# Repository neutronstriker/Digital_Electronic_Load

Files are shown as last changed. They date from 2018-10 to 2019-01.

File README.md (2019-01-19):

# Digital_Electronic_Load
An Electronic Load based on Arduino and some analog components
Components used are:
Arduino Nano-1
OLED I2C display 0.96Inch - 1
TPL0102-100PWR I2C DIGITAL PORT -1
LM358  DUAL OPAMP -1
INA226 Shunt Current / Power sensor - 1
2N3055 - NPN Power transistor -1
1 OHM / 10W resistor -1

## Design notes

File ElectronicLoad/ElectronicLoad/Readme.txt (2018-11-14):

/*
 * Readme.txt
 *
 * Created: 28-05-2016 18:02:26
 *  Author: neutron
 */ 
 I have again done the same mistake I did on PPS, I have enabled WDT in code and now I am unable to upload code because
 bootloader doesn't know about WDT. SO I have to connect USBASP and flash the nano board with the bootloader file atmega328_WD_MODS_16MHZ_57600.hex present
 in AVR Bootloader folder.

 Only then I will be able to upload code.

 I should also change the bootloaders of other nanos on the same day.

 The above thing is done on DT28-05-2016

 Dt29-05-2016:
 I faced recently a lot a device hanging issues these started earlier also but since I didnot do any extensive testing It was not being
 able to surface. So I found out that this was rarely happening because the knob button and its multiplier changing code.

 Since I had changed the wdt period to 4s instead of 2S. I figured out this was happening because of I2C bus. So I used
 different pull up resistors, As I thought 10k may be too high pull up and as a result the bus capacitance was not meeting
 the required rise time and fall time at 400khz. So I enabled internal pullups still the problem was there. So I reduced 
 the resistors to 2.2k still after sometime the problem surfaced again. 
 
 Finally I found out by checking is that INA226 was creating the problem. Because SSD1306 OLED driver has I2C internal Clamping for
 3.3V, but INA226 and TPL0102 was powered by 5V, but TPL0102 was written on event driven basis however INA226 and SSD1306 was accessed
 on loop.

 So as soon as SSD1306 was enabled I2C bus voltage was not stable it was around 3.8Vrms but after using 2.2k resistors it was 2.58Vrms
 So what I did was that I changed the supply voltage for INA226 to 3.3V it worked for sometime but again the problem started and the
 final bug was discovered which was wiring and length matching issue.  Well not exactly length matching but quite like it as Only for INA226
 the I2C SDA and SCL lines for not comming from a single point and wire lengths were not same. One wire was coming from A4, A5 pins and other
 was comming from OLED I2C pins. So one of them getting delayed.

 So I removed the I2C line which was coming from OLED i2C pin and connected from source forming a proper star configuration.

 So we should always make sure either it is a multi drop or star but make sure the I2C bus line lengths for both DATA and CLK for any device
is always same.

 So After this problem was solved so  I tried to put the supply voltage back to 5V but still there was a problem.
 So i Put it back to 3.3V.

 Now it is working but sometimes still it hangs and watchdog resets the device after 4S.

 Also the clock of I2C bus has been reduced to 100khz in order to cope up with these bus voltage and rise time issues.

 I also did the experiment of remove the gnd connection to load and then weird things started happening, even when we were supplying
 around 1mV only it was sourcing around 160mA on 5V. And when current was set went even mad.

 So I connected the ground back. 

 I also did the reverse connection test when the device was off and PPS was set to 2.5V, PPS went into OVERLOAD. Even when ELOAD was online
 PPS said OVERLOAD at 10mA set on ELOAD and Voltage on PPS 1.98V.

 I checked the bias current issue, and found that the current from OPAMP to MMBT3904 was negligibly small until saturation was hit.
 After saturation was hit it increased to a max 42mA as shown in Display by INA226 but Multimeter showed 46.5mA and also 
 I found that this means we need to calibrate either one of PPS or ELOAD. So there is a calibration issue between PPS and ELOAD.
 The extra current shown in ELOAD is not because of OPAMP output unless there in noload supply or It is saturated.

 Date:03-April-2017:
 Changed the INA226 sensor address to 0x41 in init_platform() because I am using external sensor breakout board which is programmed to do that.

 Date:03-June-2017:
 INA226 based Hang issue fixed now, it seems SCL to ina226 was not soldered properly also I changed the supply voltage of INA226 to 5V (Arduino
 NANO 5V OUTPUT) instead of 3.3V. Also enable the debounce delay in ISR0 which was disabled previously.

 Dt:29-10-2018:
 Added Serial command capability for setting current and turning on and off the load.
 This was done in a hurry for a specific task, so we will need to clean it up sometime when possible.

 Dt:14-11-2018:
 Added temp?, tset and help commands
 which will get the LM35 temperature value, set the safe operating temperature threshold and display commands usage

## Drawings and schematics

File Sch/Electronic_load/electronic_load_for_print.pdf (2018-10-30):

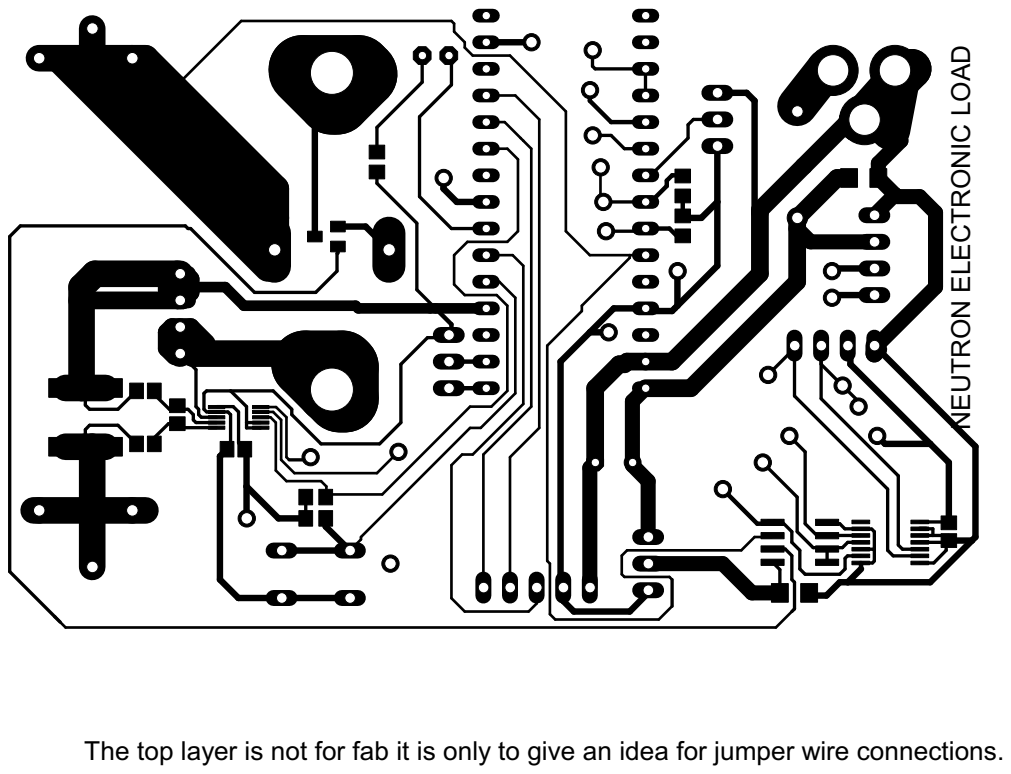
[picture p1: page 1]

The top layer is not for fab it is only to give an idea for jumper wire connections.

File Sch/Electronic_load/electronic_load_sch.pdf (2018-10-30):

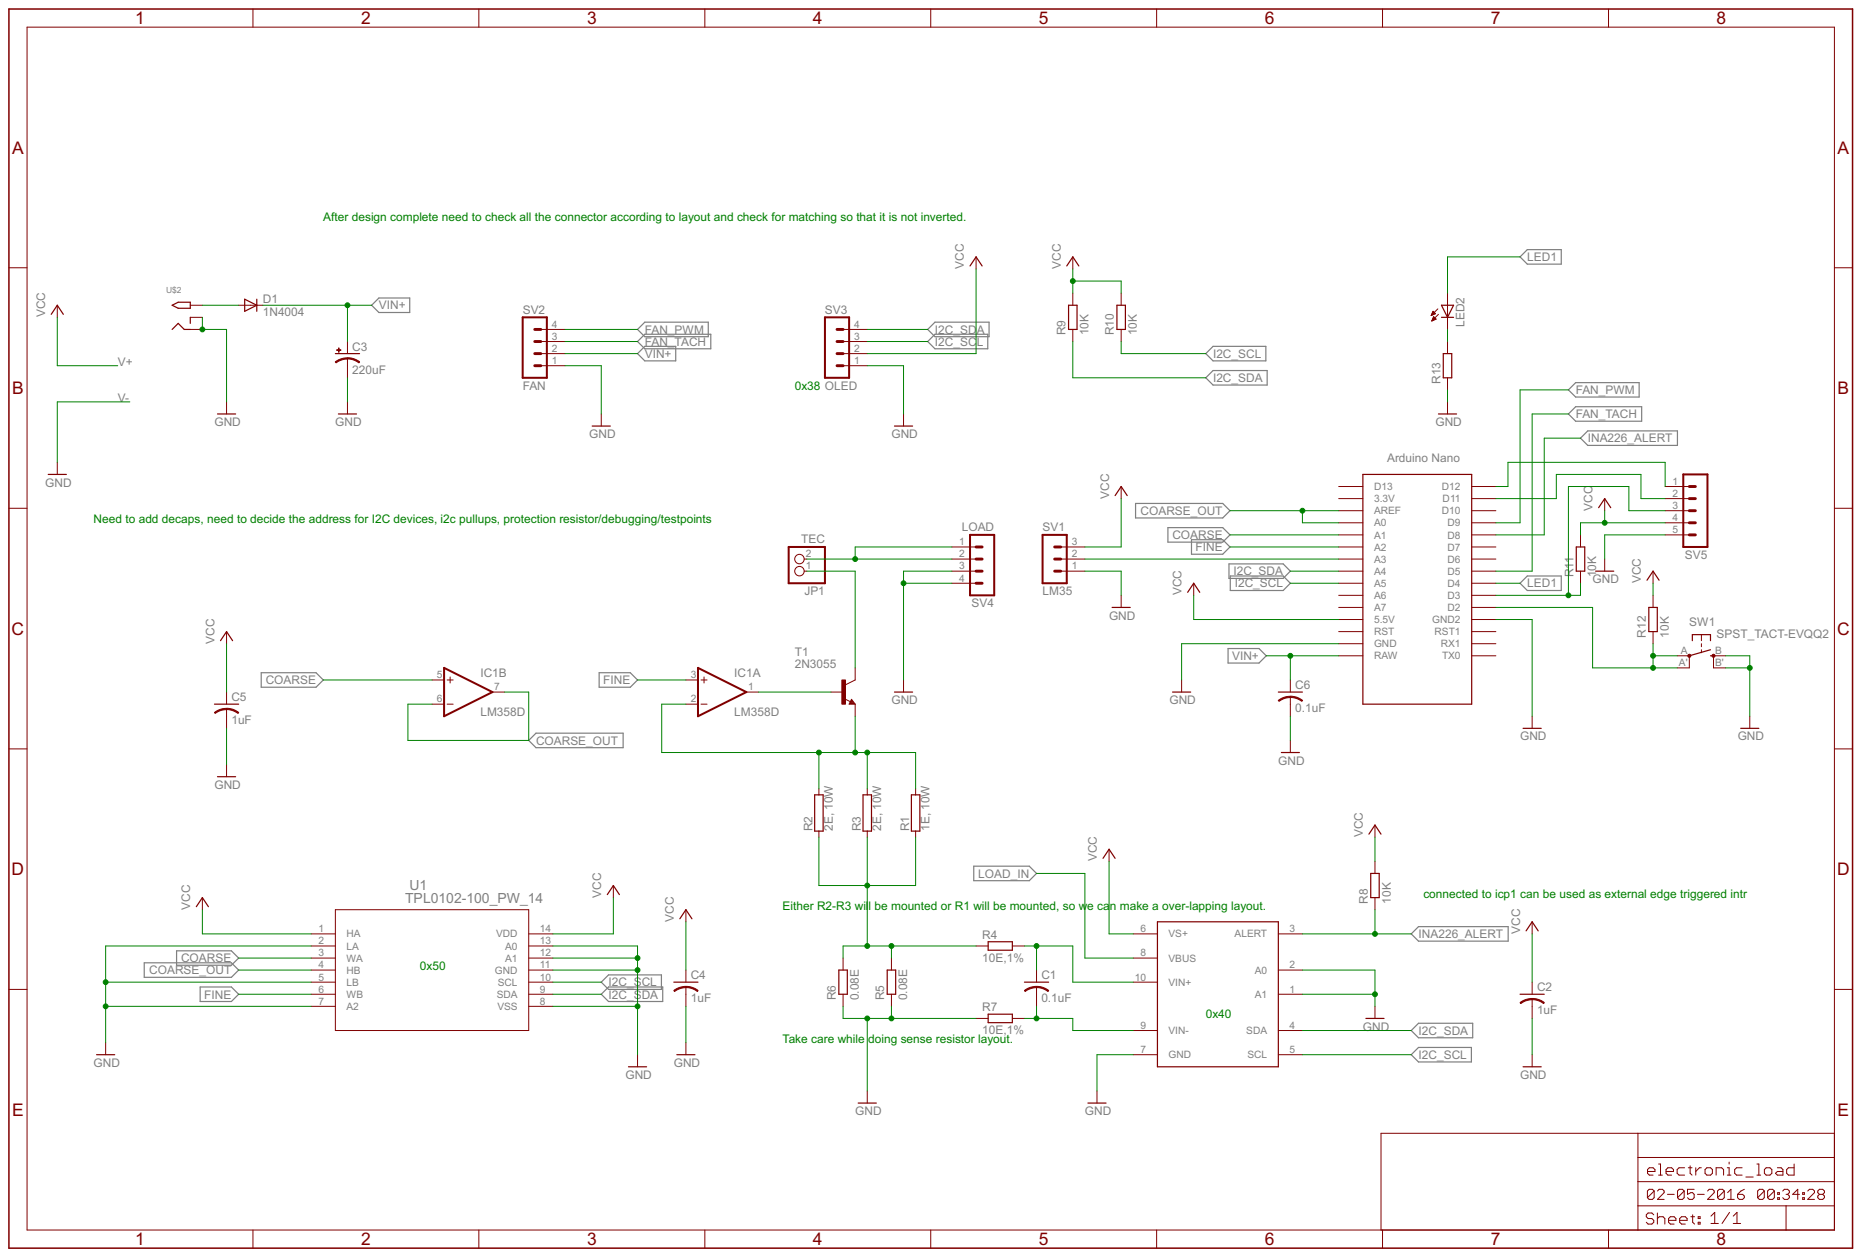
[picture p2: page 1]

After design complete need to check all the connector according to layout and check for matching so that it is not inverted.

Need to add decaps, need to decide the address for I2C devices, i2c pullups, protection resistor/debugging/testpoints

connected to icp1 can be used as external edge triggered intr

Either R2-R3 will be mounted or R1 will be mounted, so we can make a over-lapping layout.

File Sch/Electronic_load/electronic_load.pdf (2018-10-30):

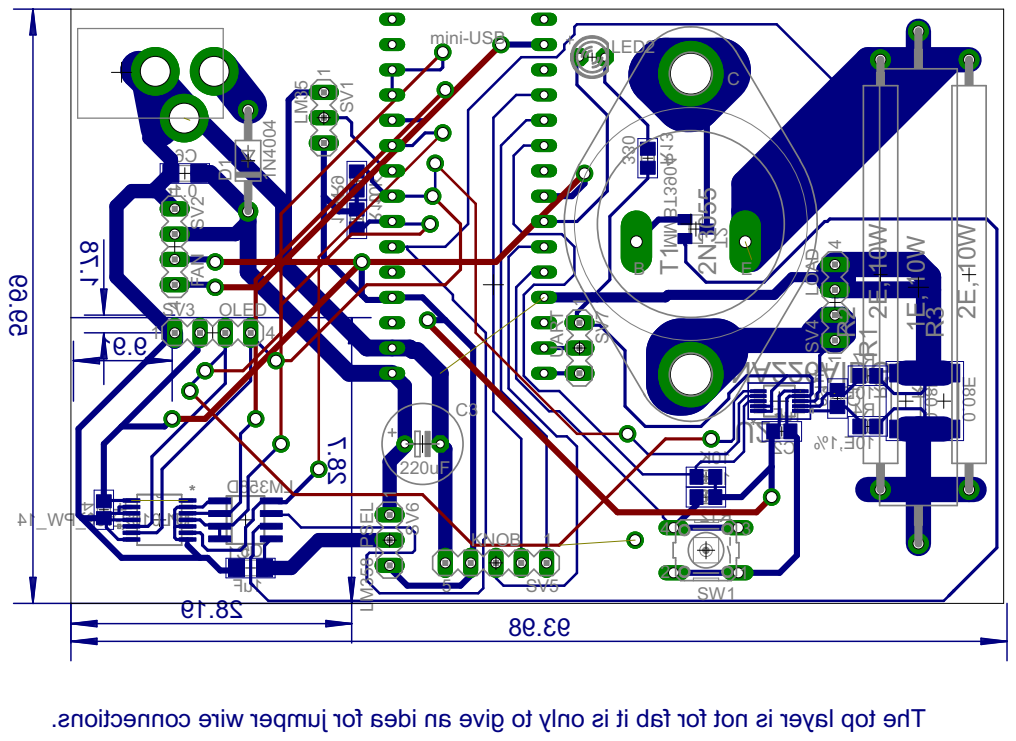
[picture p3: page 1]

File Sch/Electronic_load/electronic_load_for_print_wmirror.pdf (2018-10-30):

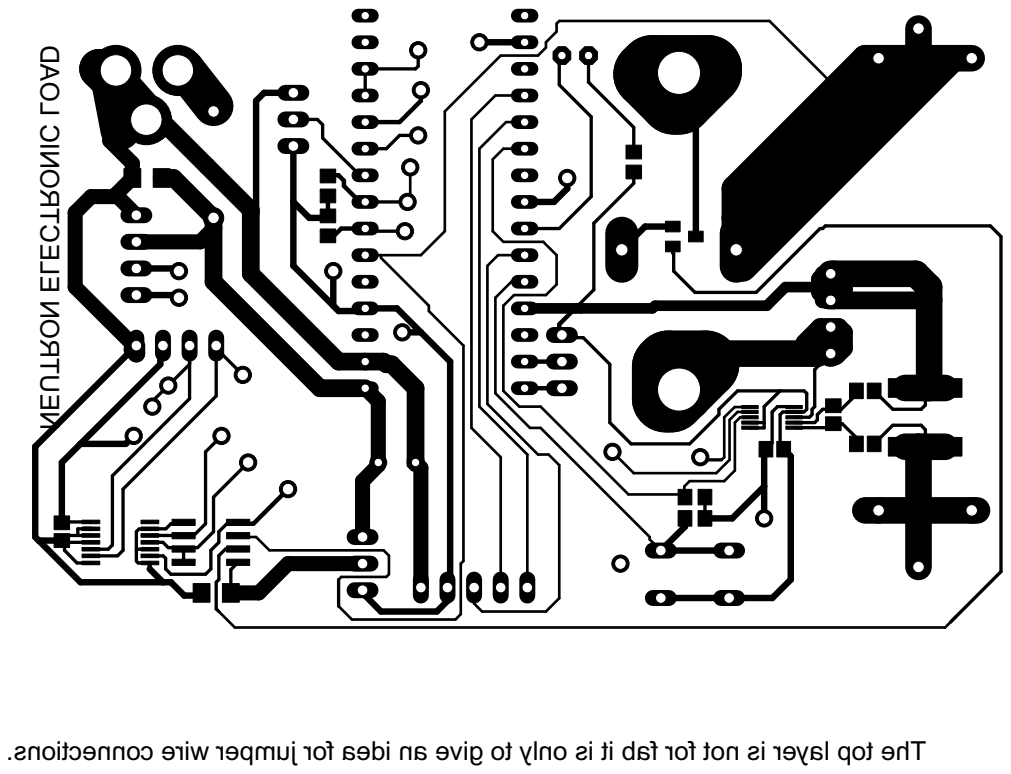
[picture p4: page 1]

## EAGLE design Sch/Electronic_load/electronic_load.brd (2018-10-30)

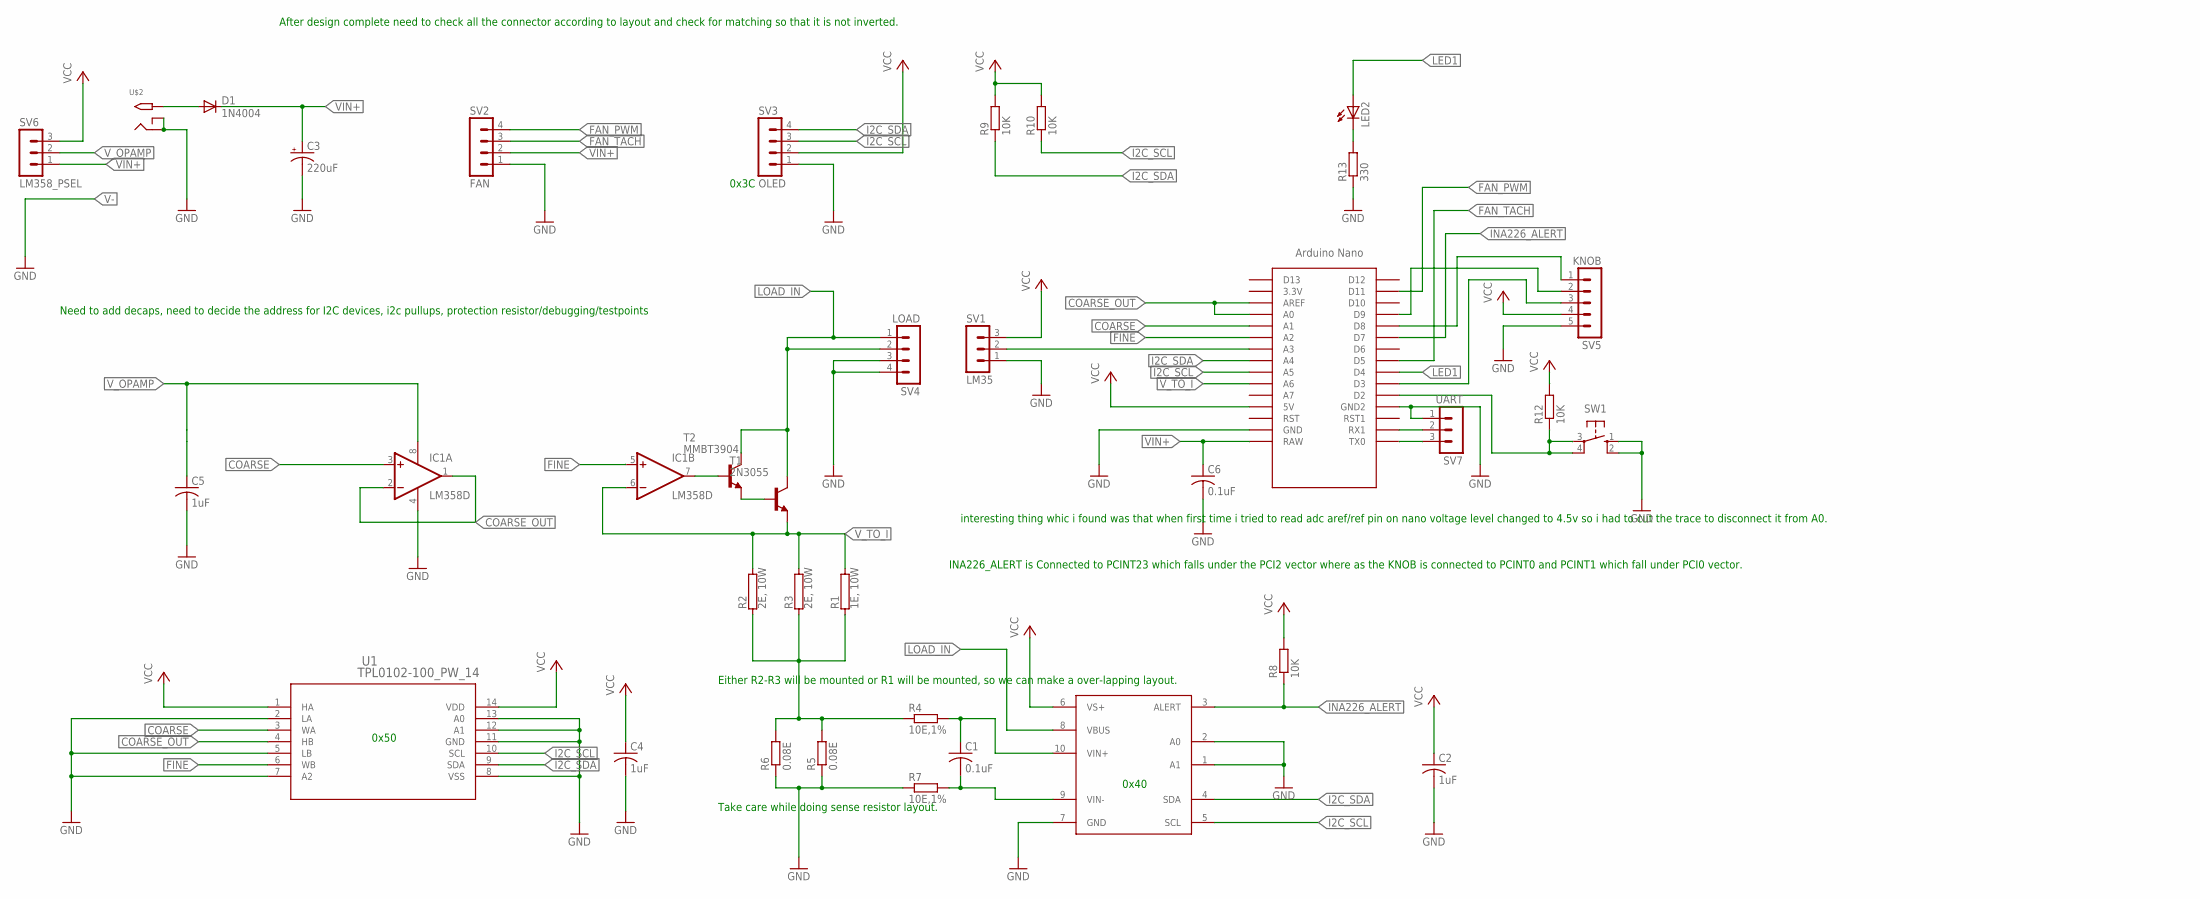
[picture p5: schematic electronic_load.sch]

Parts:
C1: 0.1uF; C0805
C2, C4: 1uF; C0805
C3: 220uF; E3,5-8
C5: 1uF; C1206
C6: 0.1uF; C1206
D1: 1N4004; DO41-10
IC1: LM358D; SO08
LED2: LED3MM
R1: 1E, 10W; AC10
R2, R3: 2E, 10W; CA4150
R4, R7: 10E,1%; R0805
R5, R6: 0.08E; R2512
R8, R9, R10, R12: 10K; R0805
R13: 330; R0805
SV1: LM35; MA03-1
SV2: FAN; MA04-1
SV3: OLED; MA04-1
SV4: LOAD; MA04-1
SV5: KNOB; MA05-1
SV6: LM358_PSEL; MA03-1
SV7: UART; MA03-1
SW1: 10-XX; B3F-10XX
T1: 2N3055; TO3
T2: MMBT3904; SOT23-BEC
U1: TPL0102-100_PW_14; PW14
U2: INA226AIDGST; SOP50P490X110-10N
U$1: NANO
U$2: 2.1MMJACKTHM; PJ-102A

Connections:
COARSE: IC1.3 (+IN), U1.3 (WA), U$1.A1
COARSE_OUT: IC1.1 (OUT), IC1.2 (-IN), U1.4 (HB), U$1.A0, U$1.AREF
FAN_PWM: SV2.4, U$1.D11
FAN_TACH: SV2.3, U$1.D5
FINE: IC1.5 (+IN), U1.6 (WB), U$1.A2
GND: C2.2, C3.-, C4.2, C5.2, C6.2, IC1.4 (V-), R5.1, R6.1, R7.1, R13.1, SV1.1, SV2.1, SV3.1, SV4.3, SV4.4, SV5.5, SV7.1, SW1.1 (S), SW1.2 (S1), U1.2 (LA), U1.5 (LB), U1.7 (A2), U1.8 (VSS), U1.11 (GND), U1.12 (A1), U1.13 (A0), U2.1 (A1), U2.2 (A0), U2.7 (GND), U$1.GND, U$1.GND1 (GND2), U$2.RING, U$2.RING_SW
I2C_SCL: R10.1, SV3.3, U1.10 (SCL), U2.5 (SCL), U$1.A5
I2C_SDA: R9.1, SV3.4, U1.9 (SDA), U2.4 (SDA), U$1.A4
INA226_ALERT: R8.1, U2.3 (ALERT), U$1.D7
LED1: LED2.A, U$1.D4
LOAD_IN: SV4.1, SV4.2, T1.C, T1.C/ (C), T2.C, U2.8 (VBUS)
unnamed: SV7.2, U$1.RX1
unnamed: D1.A, U$2.TIP
unnamed: T1.B, T2.E
unnamed: R1.1, R2.1, R3.1, R4.1, R5.2, R6.2
unnamed: C1.1, R4.2, U2.10 (VIN+)
unnamed: SV1.2, U$1.A3
unnamed: C1.2, R7.2, U2.9 (VIN-)
unnamed: IC1.7 (OUT), T2.B
unnamed: SV5.3, U$1.D3
unnamed: R12.1, SW1.3, SW1.4 (P1), U$1.D2
unnamed: LED2.K (C), R13.2
unnamed: SV7.3, U$1.TX0
unnamed: SV5.2, U$1.D9
unnamed: SV5.1, U$1.D8
VCC: C2.1, C4.1, R8.2, R9.2, R10.2, R12.2, SV1.3, SV3.2, SV5.4, SV6.3, U1.1 (HA), U1.14 (VDD), U2.6 (VS+), U$1.5V
VIN+: C3.+, C6.1, D1.C, SV2.2, SV6.1, U$1.RAW
V_OPAMP: C5.1, IC1.8 (V+), SV6.2
V_TO_I: IC1.6 (-IN), R1.2, R2.2, R3.2, T1.E, U$1.A6

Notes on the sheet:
Need to add decaps, need to decide the address for I2C devices, i2c pullups, protection resistor/debugging/testpoints
Either R2-R3 will be mounted or R1 will be mounted, so we can make a over-lapping layout.
Take care while doing sense resistor layout.
After design complete need to check all the connector according to layout and check for matching so that it is not inverted.
0x50
0x40
0x3C
INA226_ALERT is Connected to PCINT23 which falls under the PCI2 vector where as the KNOB is connected to PCINT0 and PCINT1 which fall under PCI0 vector.
interesting thing whic i found was that when first time i tried to read adc aref/ref pin on nano voltage level changed to 4.5v so i had to cut the trace to disconnect it from A0.

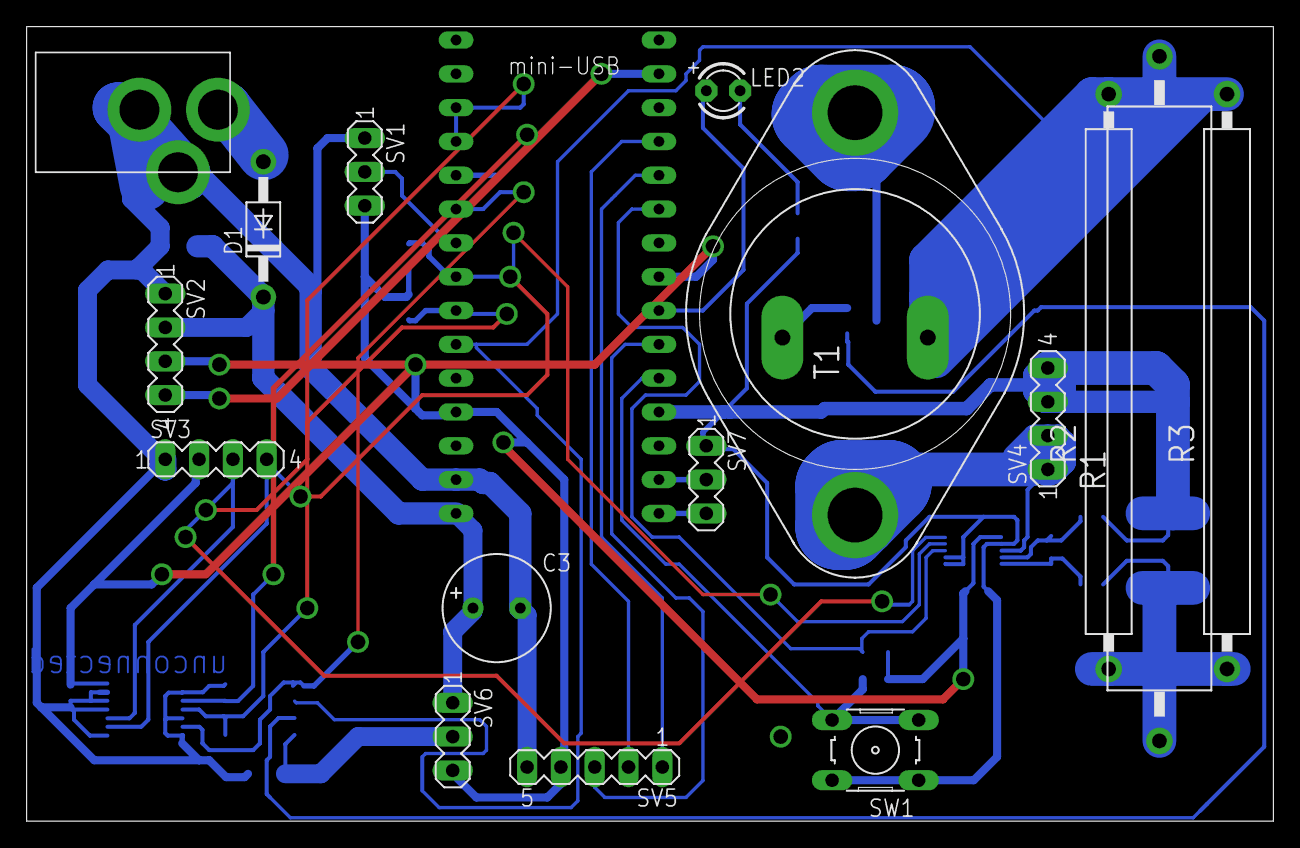
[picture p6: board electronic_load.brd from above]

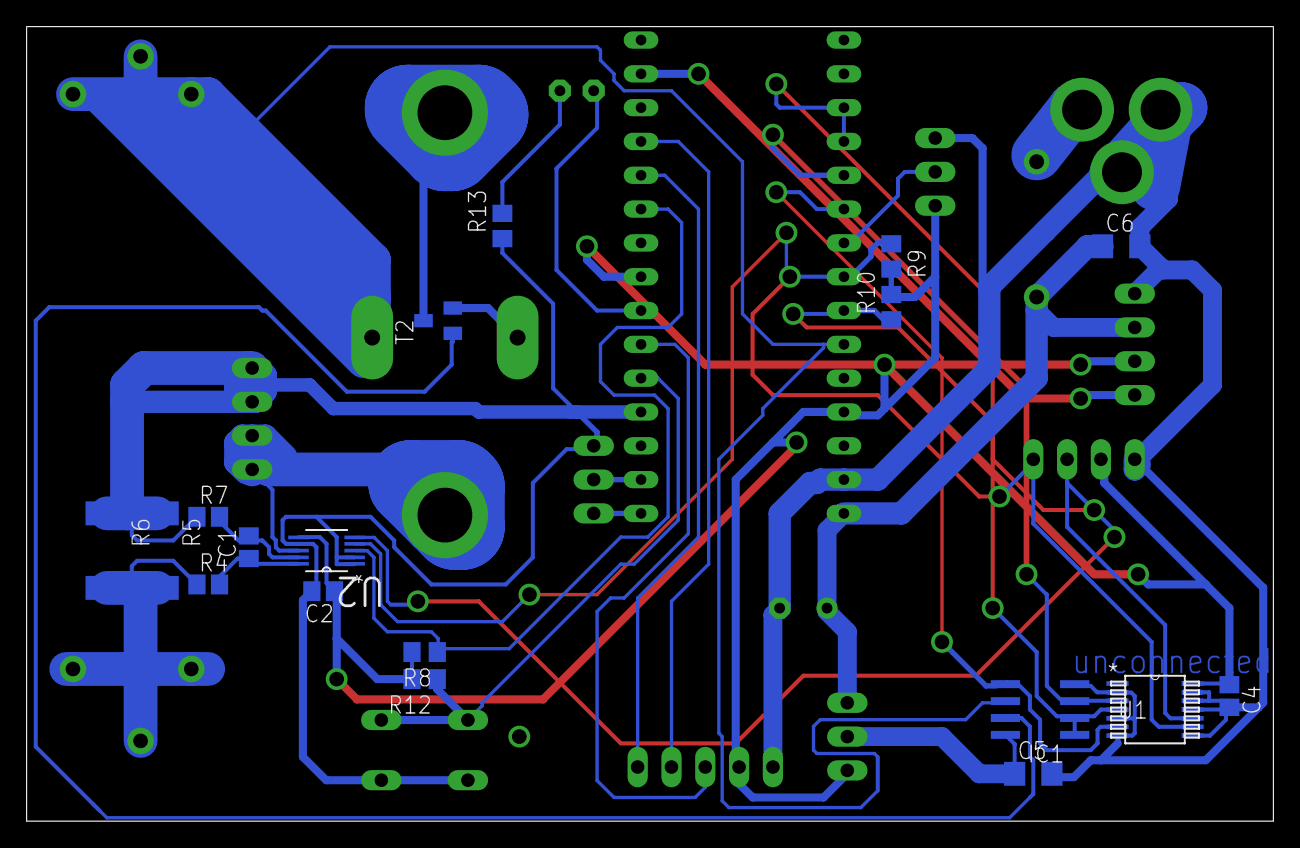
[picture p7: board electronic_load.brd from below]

Board: 2 copper layers, 93.7 x 59.7 mm, 35 parts (18 on the bottom side), 29 nets.

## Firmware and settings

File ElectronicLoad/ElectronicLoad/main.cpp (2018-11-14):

#include "config.h"

#include "Arduino.h"
//#define ARDUINO 101 //this is defined in project properties
//#define F_CPU 16000000UL //it is defined in Project properties

#include "../../uartlib.h"
#include <util/delay.h>

#include "i2c.h"

#include "GPIO.h"

#include "myStack.h"

#include "Adafruit_SSD1306.h"

#include "fifo.h"

#include "INA226.h"
//#define INA226_ADDRESS 0x40

#define OLED_ADD 0x3C

#define F_STR(x) (__FlashStringHelper*)PSTR(x) //to be used only for Arduino print class based functions

Adafruit_SSD1306 lcd;
INA226 iSensor;

void loop();
void initPlatform();
void i2c_internal_pullup(bool state);		//later this should be included in i2c_lib
void showPinOut();

void anti();
void clockwise();


GPIO blueLed(4);
GPIO redLed(13);
GPIO knob_clk(9);
GPIO knob_dat(7);
GPIO knob_btn(3);//knob_btn(4);

uint16_t pc0=0;
uint16_t pc2=0;
uint8_t state=0,data;

fifo_byte buffer(16);

#define CLOCK		2
#define ANTICLOCK	3

#define POT_CHANNEL_A	0
#define POT_CHANNEL_B	1

#define COARSE_ADC_CH		A0
#define COARSE_BUF_ADC_CH	A1
#define FINE_ADC_CH			A2
#define V_TO_I_ADC_CH		A6
#define TEMP_ADC_CH			A3

uint32_t btn_sw_interval=0;
#define BUTTON_DEBOUNCE_DELAY	200 //200 Milli Seconds 
#define DISPLAY_UPDATE_PERIOD	50	//30 Milli Seconds

#define ANALOG_REF_VOLTAGE_mV		5000			//5000 for external power and 4320 for USB.
#define ANALOG_2_VOLT_MULTIPLIER	((float)ANALOG_REF_VOLTAGE_mV/1023)		//but I doubt this would be in float, which would introduce more error.
																			//now solved by type casting.		
																			//by making the analog ref variable we may not need to have different
																			//function arrangements while changing AVref source.

#define ANALOG_REF_VOLTAGE_INTERNAL_mV	1100
#define ANALOG_2_VOLT_MULTIPLIER_INTERNAL	((float)ANALOG_REF_VOLTAGE_INTERNAL_mV/1023)

#define RESISTOR_VALUE			(float)1.17				//1.12 OHMS

uint8_t pot_channel = POT_CHANNEL_A;

void pot_decrease(uint8_t channel);
void pot_increase(uint8_t channel);

uint8_t pot_channel_val[2]={0};
char channel_code[2]={'A','B'};

#define TPL0102_ADDRESS	0x50		//When all Address pins grounded

uint16_t conv_2_volts(uint8_t adc_channel, uint16_t vref_in_millivolts);
void displayUpdate();
uint32_t display_update_interval=0;

void resetPots();

float getSupplyVoltage();
float supplyVoltage=5000;		//in milli-Volts, default value is 5000mV

int setLoadCurrent(uint16_t current);
uint16_t iValueSetting=0;
void increase();
void decrease();
uint8_t temperature;

GPIO output_sw(2);
uint8_t loadON=0;

uint8_t int1_count=0;
uint16_t knob_click_value=1;		//default click value is 1 per knob click in any direction.

#include <avr/wdt.h>

#define	ABSOLUTE_MAX_TEMP	90
#define	WARNING_TEMP		60

uint8_t activeLoadTempThreshold = ABSOLUTE_MAX_TEMP;

#define MAX_SUPPORTED_CURRENT 2000		//in mA
#define ACTIVE_LOAD_TJ_C		150		//in Degree celcius, actual max is 200, but the sensor LM35 supported value is 150, and further more there will be Rjc

//there are two errors because of which my reading were not matching, 
//1.The Voltage ref of VCC is not constant 5000mV as a result the multiplication factor 4.88 to get voltage is not proper
//2.The 1 OHM resistor is not exactly 1 OHM it is around 1.12 OHMs 

//I found that voltage measure on Nano when connected to my computer was 4.12Volts, could be because of IR drop of USB cable
//also maybe some diodes in series on the board and Current was around 100mA at peak.

//Also I didn't find any loading when I tested second channel at 50% and read value was same as calculated value, se we can
//say that there was no loading, atleast not with LM358.

//There are some more comments about the test results which you can find in the schematic called "current controller"(multisim).

//Another thing to notice was that the peltier junction device when connected in series didn't let the current more than 630mA@5V
//because it might have heated up as a result its resistance increased and capped the current draw capacity.

//My current capacity was earlier capped at 1.3A@5V, So I checked in multisim simulation that the opamp needs to provide around 40mA
//to able to draw around 3A@5V which I think technically is not possible because LM358 is rated for around 20mA otherwise output will be 
//start drooping. So I thought by increasing the gain of Transistor I could reduce the current draw so I planned to use BC549 as 
//darlington input stage for 2N3055, but it still didn't work, I thought of another idea to use TWO opamps with outputs coupled
//to be able to drive the 40mA current. But now I just checked that the voltage drop because of my test cable itself was more than
//2.5V So it was obvious that current couldn't be increased. I had also planned to increase the OPAMPS supply voltage at a point
//so that its output voltage should not get affected by its RAIL limit.

//Even when the wire was changed I couldn't reach much higher currents so I increased the opamp voltage as a result I was able to
//reach higher current. By increasing the Opamp voltage I was able to increase the current to 2.03A@4.8V. However it should be noted
//that the when I was using even short good wires the internal resistance of the internals of PSU dropped the voltage to 4.5V when
//it was actually showing 5V@1.2A. So even if my voltage was 4.8V it should have been actually 4V or less.
//DT:29-05-2016
//Find updated answers to this in Readme log.


//DT:19-05-2016:
//after assembly need to test if it we can run the device even by disconnecting the trace between GND and LOAD section.
//also need to see the resistor value if needs to be calibrated for current sensor, but there is chance that the small amount of current
//extra shown by the load meter could be because of the basecurrent flowing from the LM358 Opamp output into the MMBT3904 and then to the 2N3055.
//DT:29-05-2016
//Find updated answers to this in Readme log.


//////////////////////////// copied from DDAT LAtest; done in a hurry; fix later //////////////////////
#define CMD_REPLY_BUFFER_LENGTH		64		//initially it was 32, but in order to accommodate i2cwrite instruction, it has been increased to 64.

char btCmdReplyBuffer[CMD_REPLY_BUFFER_LENGTH]={0};
uint8_t uartBufCharCount=0;

//lets try to keep all command keywords within 4 letters, to improve performance by reducing search time,
//however it will be better if we can using strcmp_P and make sure that commands are executed when followed by cr,lf etc. --done
const char PROGMEM cmd1[]="iset";		//set current value
const char PROGMEM cmd2[]="ion";		//turn on load
const char PROGMEM cmd3[]="ioff";		//turn off load
const char PROGMEM cmd4[]="stat?";		//will return status ON or OFF
const char PROGMEM cmd5[]="iset?";		//will return iset value
const char PROGMEM cmd6[]="ibus?";		//will return ishunt value
const char PROGMEM cmd7[]="vbus?";		//will return vbus value
const char PROGMEM cmd8[]="temp?";		//will return the temperature of the active load
const char PROGMEM cmd9[]="tset";		//set the safe temperature limit of the active load
const char PROGMEM cmd10[]="help";		//will print available commands and their usage
const char PROGMEM cmd11[]="tset?";		//will print the current safe temperature setting value


void readSerialCmd();
uint8_t readUntilToken(char* buffer, uint8_t token, uint8_t maxlen);
void replyOK();
void usage();

uint8_t case_sensitivity_status=0;

uint8_t backspace_det=0;

float iShuntVal = 0;
float vBusVal = 0;

////////////////////////////////////////////////////////////////////////////////////////////////


int main(void)
{
	wdt_reset();		//reset Watchdog timer
	wdt_disable();
	wdt_enable(WDTO_4S);	//enable Watchdog timer with a Value of 2 seconds, It was earlier affected a lot because of 
	//i2c bus delays because of higher pullup values. Now solved by using enabling software pullup also.
	
	
	initPlatform();		//Initialize all platform devices like UART and Display and other peripherals.
	

	
	while(1)
	{
		readSerialCmd();
		loop();
		if (serialEventRun) serialEventRun();	//Polls the Serial port for new data and updates Buffer accordingly
												// if serialEvent() function is used
	}

	return 0;
}

void initPlatform()
{
	init();	//Initialize Arduino Core
	
	Serial.begin(57600);//increases a lot or Ram and Rom usage disable after diagnostics and recompile.
	
	Serial.print(F_STR("ELECTRONIC_LOAD_INITIALISED\r\n"));
	
	i2c_init(I2C_BUS_CLK);	//it is called with 400Khz by adafruit display lib so not necessary any more, but before display is initialized many other I2C devices are
	//also initialized so we call it here. It is fine though to be set twice not a big deal
	
	i2c_internal_pullup(true);	//If this is not enabled BUS hangs most of the times. So this has enabled. Maybe pullup value is too high
	//so heavy bus capacitance of three devices is not being handled by 10k resistors alone, I should have used 4.7k or less value
	//same change should be done in PPS also.
	//this is not required since pullups are present in LCD board, however
	//if we add more devices to bus we should add external pull-ups.	Find updated answers to this in Readme log.

	#ifdef INA226_ENABLE

		iSensor.begin(INA226_ADDRESS);

		iSensor.configure(INA226_AVERAGES_4, INA226_BUS_CONV_TIME_204US, INA226_SHUNT_CONV_TIME_8244US, INA226_MODE_SHUNT_BUS_CONT);
	
		// Calibrate INA226. Rshunt = 0.04 ohm, Max excepted current = 2A ,Resistor Calibration value has been compensated by calibration with source meter
		iSensor.calibrate(0.0388, 2);
	//DT:29-05-2016
	//Find updated calibration need info to this in Readme log.

	#endif

	knob_clk.setInput();	//set knob pins as input
	knob_dat.setInput();
	knob_btn.setInputPullUp();		//set Knob Button as Input Pullup.

	PCMSK0 = (1<<PCINT1) | (1<<PCINT0);	//set PCI on digital Pin 8 & 9, an change on either pins of encoder triggers IRQ.
	PCICR = (1<<PCIE0);					//Enable the PCI0 IRQ
	
	
	
	supplyVoltage = getSupplyVoltage();
	Serial.print("Supply Voltage is: ");
	Serial.println(supplyVoltage);
	
	
	
	blueLed.Low();
	redLed.Low();
	
	output_sw.setInputPullUp();		//Hardware Pull up resistor Pad got disconnected so software pullup used.
	EICRA = (1<<ISC01);// | (1<<ISC11); //INT0 & INT1 Trigger on Falling edge
	EIFR &= ~(1<<INTF0);// | (1<<INTF1));		//bootloader might have enabled INT0/INT1 So clear the FLAG first otherwise this will set an IRQ @ Power On.
	EIMSK = (1<<INT0);// | (1<<INT1);	//ENABLE INT0 & INT1
	
	resetPots();	//reset Dpot Channel A and B., when it is placed just after i2c_init and i2c Pull up enable
	//i dont know why it makes TPL0102 go mad maybe i2c bus stability issue. but even after issuing delay it did not solve.
	
	
	lcd.begin(SSD1306_SWITCHCAPVCC, OLED_ADD);
	
	lcd.dim(true);//dim the display brightness
	lcd.clearDisplay();
	lcd.setCursor(0,0);
	lcd.setTextColor(WHITE);
	lcd.setTextWrap(true);
	lcd.setTextSize(2);
	lcd.println(F_STR("  NEUTRON"));
	lcd.println();
	lcd.print(F_STR("ELECTRONIC"));
	lcd.println(F_STR("   LOAD"));
	lcd.display();
	
	delay(2000);		//delay to show Boot text
	
	
	

	
	
	

}

void loop()
{
	
	wdt_reset();		//reset WatchDog Timer, If this loop hangs anywhere and gets stuck for more than 2 seconds it will reset the device.
	
	static uint16_t iValLastState=0;
	
	static	uint32_t warningLedTogDelay = 0;
	#define	LED_BLINK_DELAY	400			//400mS Led Blink Delay
	
	//static uint32_t output_sw_debounce_delay=0;
	
	temperature = (ANALOG_2_VOLT_MULTIPLIER_INTERNAL*analogRead(TEMP_ADC_CH))/10;		//temperature logging.
	
	
	//////////////////////////// OUTPUT ENABLE SWITCH LOGIC //////////////////////////////
	if(loadON)
	{
		if (temperature < activeLoadTempThreshold)		//temperature less than 90 degree celcius.
		{
			
			
			if (iValLastState != iValueSetting)
			{
				iValLastState = iValueSetting;
				setLoadCurrent(iValLastState);
			}
			
			
			if ((temperature > WARNING_TEMP) && ((millis()-warningLedTogDelay) > LED_BLINK_DELAY) )
			{
				blueLed.toggle();
				warningLedTogDelay = millis();
			}
			else if (millis()-warningLedTogDelay > LED_BLINK_DELAY)
			{
				blueLed.High();
			}
			
			
		}
		else
		{
			loadON = 0;		//Turn OFF DEVICE When temperature exceeds "activeLoadTempThreshold"
		}
		
		
	}
	else
	{
		if (iValLastState != 0)
		{
			setLoadCurrent(0);
			//resetPots();
			iValLastState = 0;
		}
		blueLed.Low();
	}
	
	
	/*
	//////////////////////////// OUTPUT ENABLE SWITCH LOGIC //////////////////////////////
	if (!output_sw.getState() && millis()-output_sw_debounce_delay > BUTTON_DEBOUNCE_DELAY)
	{
		loadON = !loadON;			//we will put this part in INTR so that no re-triggering happens(on button hold) and also it will be edge triggered
									//so no de-bouncing required.
		output_sw_debounce_delay = millis();
	}
	*/
	
	
	
	/////////////////////////////////// KNOB MULTIPLIER CODE //////////////////////////////////////////	
	if(!knob_btn.getState() && millis()-btn_sw_interval>BUTTON_DEBOUNCE_DELAY)
	{
		//pot_channel = !pot_channel;		//by switch Press Toggle Between POT Channels.
			int1_count++;
			
			if (int1_count == 4)
			{
				int1_count = 0;
			}
			
			knob_click_value = 1;
			
			for (uint8_t i=0;i<int1_count;i++)
			{
				knob_click_value *= 10;
			}

		btn_sw_interval = millis();
	}
	
	
	


	
	//////////////////////////////////// KNOB DIRECTION DECODER ////////////////////////////////////////////
	
	uint8_t test;
	if(!buffer.isEmpty())
	{
		test = buffer.deque();
		
		if(test == ANTICLOCK)
		{
			
			//pot_decrease(pot_channel);
			//anti();
			decrease();
		}
		else if (test == CLOCK)
		{
			//pot_increase(pot_channel);
			//clockwise();
			increase();
		}
		
	}
	
	displayUpdate();
	
	
}


void displayUpdate()
{
	if(millis()-display_update_interval > DISPLAY_UPDATE_PERIOD)
	{
		lcd.clearDisplay();
		lcd.setTextColor(WHITE);
		lcd.setTextSize(2);
		lcd.setCursor(0,0);
		
		lcd.setTextWrap(false);
		
		/*
		lcd.print("POT-");
		lcd.print(channel_code[pot_channel]);
		lcd.print(':');
		lcd.println(pot_channel_val[pot_channel]);
		*/
		
		uint8_t arr[4]={0};
		uint8_t pos=0;
		uint16_t temp = iValueSetting;
		lcd.print("Iset:");
		
		//lcd.println(((float)iValueSetting/1000),3);
	
		while(temp>0)
		{
			arr[pos]=temp%10;
			temp/=10;
			pos++;
		}
		
		for(uint8_t i=4;i>0;i--)
		{
			if (i-1 == int1_count)
			{
				lcd.setTextColor(BLACK,WHITE);
			} 
			else
			{
				lcd.setTextColor(WHITE);
			}
			lcd.print(arr[i-1]);
			
			if (i==4)
			{
				lcd.setTextColor(WHITE);
				lcd.print('.');
			}
			
		}
		
		lcd.println();
		
		
		lcd.setTextColor(WHITE);
		lcd.print(F_STR("Cur:"));
		
		#ifdef INA226_ENABLE
			iShuntVal = iSensor.readShuntCurrent();
			lcd.print(iShuntVal,3);
		#endif
		
		lcd.print('A');
		
		lcd.setCursor(0,34);
		lcd.print(F_STR("Vin:"));
		
		#ifdef INA226_ENABLE
			vBusVal = iSensor.readBusVoltage();
			lcd.print(iSensor.readBusVoltage(),2);
		#endif
		lcd.print('V');	
		
		/*
		lcd.setCursor(0,50);
		lcd.print(F_STR("Pow:"));
		lcd.print(iSensor.readBusPower(),2);
		lcd.print('W');
		*/
		
		
		analogReference(INTERNAL);
		
		lcd.setCursor(0,50);
		lcd.print(F_STR("Temp:"));
		lcd.print(temperature);
		lcd.print("C");
		
		//here code to read back Analog data and print on LCD.
/*		
		lcd.setTextSize(1);
		lcd.println();
		
		lcd.print("A0:");
		lcd.print(ANALOG_2_VOLT_MULTIPLIER*analogRead(A0));
		lcd.print(" A6:");//A1
		lcd.print(ANALOG_2_VOLT_MULTIPLIER*analogRead(A6));
*/		
		lcd.display();
		
		display_update_interval = millis();			//remember delays can cause problems for knob. so we use millis to do this.
													//or even better try reducing ADC freq, but see that reducing ADC freq doesn't
													//add to the delays.(it won't if it is Interrupt based)
													//Another important thing to note is that on these Arduino Mini, Nano
													//board the ADC is pretty Noisy because they don't have separate Supplies for 
													//AVCC a we have on-our boards which is filtered through a LC filter.
													//Here all VCC lines are coupling together as a result the Switching noise
													//of Supply Line are coupled to it. However there might also be significant
													//contribution because of the Reference taken as VCC.
													
													//So we have to make an intelligent algorithm which will take Reference as
													//VCC until we reach below 1V, then it will switch internal BG Voltage 1.1V
													//for Channel A, and for Channel B, it will Always take Vref-EXT as Reference
													//we have to sufficient delays for Internal Voltages to stabilize after changing
													//reference source.
													
													//but point to be noted is that I don't think it will be of much help of using
													//Vref-EXT connected to WA-POTA since ATMega328 Datasheet Specifies that the VRef
													//-EXT cannot go below 1V.
	}
}




void i2c_internal_pullup(bool state)
{
	GPIO sda(A4);
	GPIO scl(A5);
	
	if(state == true)
	{
		sda.setInputPullUp();
		scl.setInputPullUp();	
	}
	else
	{
		sda.setInputPullDown();
		sda.setInputPullDown();
	}
}

void reset_millis()
{
	
	extern volatile unsigned long timer0_overflow_count;
	extern volatile unsigned long timer0_millis;
	timer0_overflow_count=0;
	timer0_millis=0;
	
}

uint16_t minutes()
{
	return (millis()/1000)/60; //check this that division operation can seriously decrease performance
                            //because there is not hardware division algorithm
                            //try to take minutes and seconds as global values and run only seconds that will update
                           //the minutes value also once in every 60 seconds instead of once on every call.
}

uint8_t seconds()
{
	return (millis()/1000)%60; //check this that modulo operation can seriously decrease performance
}                               //find an optimized way try a mix of >> and subtraction instead


ISR(INT1_vect)
{
	/*
	while(!knob_btn.getState());
	int1_count++;
	
	if (int1_count == 4)
	{
		int1_count = 0;
	}
	
		knob_click_value = 1;
		//this area is very buggy. If you push the button too fast or immediately after pressing this
		//you start turning knob then wdt_reset() can't be executed and system will reset so, we need
		//to find a  solution for this. Also it is not working very well, very unstable.
		//another thing which I have noticed is that the wires below it are by chance getting shorted
		//and re-triggering this IRQ. we should use some insulation below it.
		
		//For better stability we can make this portion of code into polled instead of IRQ driven.
		for (uint8_t i=0;i<int1_count;i++)
		{
			knob_click_value *= 10;
		}
	*/
//	_delay_ms(100);		//noise cancellation delay
}

ISR(INT0_vect)
{
	loadON = !loadON;
	while(!output_sw.getState());
		_delay_ms(5);		//noise cancellation delay, using delay in the interrupt causes the device to hang sometimes
}

ISR(PCINT0_vect)
{
		
	data = PINB & 0x03;
	if(state != data)
	{
		if(data == 0)
		{
			if(state == 1)
			{
				buffer.enque(ANTICLOCK);
			}
		}
		else if (data == 1)
		{
			if (state == 0)
			{
				buffer.enque(CLOCK);
			}
			
		}
		else if (data == 3)
		{
			if (state == 2)
			{
				buffer.enque(ANTICLOCK);
			}
			
		}
		else if (data == 2)
		{
			if (state == 3)
			{
				buffer.enque(CLOCK);
			}
			
		}
		
		//try adding low pass filter to reduce glitch--done
		state = data;		//added a low pass filter but even that couldn't help much.
		
	}
	
	//I understood that when Inside this ISR the delay() doesn't work properly but it works as opposed what I thought previously
	//that it will get stuck but surprising I saw that it was working but maybe it wasn't working as it was supposed but in a 
	//an irregular way, for example the 100mS specified delay might would have taken even longer than 100.
	
	
	//I found it you can read the micros() def which is used by delay() now in that there is a condition which checks if TIFR flag
	//is cleared or up for the current run when TCNT value is less than 255 but since we are inside the ISR the timer_ISR wont
	//execute as a result the flag wont be cleared as a result the variable 'm' is always increment on each call to micros()
	//as a result the delay() ends up sooner that it should be, that is why when I used 100millisecond delay using _delay_ms()
	//it doesn't work that well.
	
	//May be I have not fully understood that yet, it seems that the 'm' value is always reloaded from timer_0_overflow_count
	//which will not increment if timer0ISR doesn't run. So the only way I think to find out the cause of early exit of delay
	//instead of getting stuck is by doing a debug. (For debug we have to write a minimal code, use Timer2 ISR and use delay with 
	//in that). We cannot use any communication polling stuff like I2C or SPI, absolutely minimal code.
	
	//another thing to note is that since now program complexity has slightly grown which eventually slows down thing even without
	//any delay here it works fairly well and stable.
	
	//_delay_ms(5);
	//delay(100);				//now the delay works here. but doesn't improve much still can try the low pass, but you can disable this delay and slowly move the knob to see the bounce effect.
					//you can also experiment by choosing only one pin as INT source instead of both.--done--didn't help.
					//100ms is the most optimal delay, below or above this can make the system unstable.
		
		//even though when moving it very fast it slips, and sometimes shows a few anti-clocks, in real-life implementation
		//we will not count how many anti-clocks and clocks it turned, but if it turned really fast in one direction
		//and go a few glitches of the opposite direction, take it this way like while increasing from 0 to 100 it will
		//increase from 0 to 97 instead because 100 fast turns  + a few glitches in opposite direction
		//but we won't be able to notice it. So it won't matter at all at that speed.
}
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

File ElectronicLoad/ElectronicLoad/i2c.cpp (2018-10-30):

/*
 * i2c.cpp
 *
 * Created: 31-05-2015 00:32:00
 *  Author: neutron
 */

#include "i2c.h"

uint16_t timeout_val = 2000; //2 seconds default can be modified later
uint32_t time_stamp=0;

int i2c_init(unsigned long i2c_clk)
{

	unsigned int TWBR_VAL;

	//from i2c clk calculation formula and works only when TWPS is zero

	TWBR_VAL = ((F_CPU/i2c_clk)-16UL)/2UL;

	//this means that the value of TWBR has gone above 255 i.e. it won't fit in
	//an 8 bit register like TWBR  so this is an error so we return -1 to
	//notify the error.
	if(TWBR_VAL > 255)
		return 0;

	TWSR = 0; //clear all the TWPS bits //however Status bits TWS3-7 won't be
	//affected since they are read only bits.

	TWBR = TWBR_VAL;//load value generated from the calculation into TWBR

	TWCR  = (1<<TWEN); //enable the TWI module in AVR
	//note we don't need to set the functionality of SDA and SCL pins
	//(i.e. SDA is PC4 and SCL is PC5 in 28pin AVRs)  because the when
	//we enable TWI module those pins are overriden by TWI module and
	//are in OPENDRAIN mode.

	return TWBR_VAL;//notify the I2C has been Initialised successfully.
}


//A note about the TWINT flag:
/* TWINT is short for TWI interrupt flag, when the TWI unit in AVR completes
an job(one operation) its sets TWINT flag high. So if Global Interrupt flag is
also set along with TWIE(TWI interrupt enable bit) in TWCR then it can trigger
an interrupt.

The TWI module in AVR cannot proceed to do any operation if TWINT flag is set
in TWCR so to do any operation we must clear the TWINT flag by writing ONE to it.

When the TWINT flag is set the TWI module of AVR pulls the SCL line LOW irrespective
of whether it is in MASTER mode of SLAVE mode. There by allowing the SOFTWARE to
respond to the JOB COMPLETION notification.

IF interrupts are not enabled then after Writing appropriate data to respective
TWI registers and clearing the TWINT flag by writing ONE to it. We must keep polling
the TWINT flag in TWCR to know when the Transmission has completed or if any new data
is received or have received a STOP or START condition.

When ever the TWINT flag is set we must check the TWS3-7 status bits in TWSR to know the
status of TWI unit and proceed according to it.

*/

int i2c_start()
{
    //transmit a start condition.
	TWCR = (1<<TWEN) | (1<<TWSTA) | (1<<TWINT); //clear the TWINT flag while doing any operation
    
	time_stamp=millis();
    
    while(!(TWCR & (1<<TWINT))) //wait until operation is complete by polling TWINT flag.
    {
	    if((millis()-time_stamp)>timeout_val)
	    {
		    return 2; //device timed out, take care of error handling in the calling function.
	    }
    }

	if((TWSR & 0xF8) != TW_START) // TW_START is the definition for START condition defined in
		return 0;				//in <util/twi.h> we are masking the first three bits in  TWSR because
		//first two bits are TWPS(prescaler bits) and third bit is reserved.

	return 1; //return 1 means success
}

int i2c_rep_start()
{
	//Repeated start and Start have different status code despite being the same kind of
	//operation they leave a different imprint in the status bits of TWSR

	

	TWCR = (1<<TWEN) | (1<<TWSTA) | (1<<TWINT);
	
	time_stamp=millis();
   	
	while(!(TWCR & (1<<TWINT))) //wait until operation is complete by polling TWINT flag.
	{
		if((millis()-time_stamp)>timeout_val)
		{
			return 2; //device timed out, take care of error handling in the calling function.
		}
	}
	if((TWSR & 0xf8) != TW_REP_START)
		return 0;

	return 1;
}


void i2c_stop()
{
	//transmit a stop condition.
	TWCR = (1<<TWEN) | (1<<TWSTO) | (1<<TWINT);

	//we cannot poll the TWINT flag to check whether the stop condition was transmitted or not

	//And neither can we check the status code register.

	//Another point to keep in mind is that after sending a stop condition we will
	//in any case send a start condition first and in the start condition function
	//we are checking if the start condition was transmitted successfully or not.

	//And also if we transmit a stop condition when we are in control of the bus
	//the connected slave inhibits all operations and stops communication.
	//So we don't need to worry that the slave will may transmit data after sending
	//a stop cmd and it may be lost. But if we send a STOP while the slave is transmitting
	//then it could be an illegal case.
}


unsigned char i2c_transmit(unsigned char data)
{
	
	do{

		TWDR = data;

	}while(TWCR & (1<<TWWC)); //load the data into TWDR and also check if any write collision
	//occured if there is any collision then keep writing the data into TWDR until
	//there is no collision. It is optional as if in all routines we wait until TWINT is high
	//then there is no need of this.

	//Write collision occurs when we try to write data to TWDR when TWINT is low.
	//The TWWC flag is cleared automatically on writing to TWDR when TWINT is high.

	TWCR = (1<<TWINT) | (1<<TWEN); //Clear the TWINT flag and keep I2C unit enabled
	//so that data is transmitted in the next cycle.

	time_stamp=millis();
	
	while(!(TWCR & (1<<TWINT))) //wait until operation is complete by polling TWINT flag.
	{
		if((millis()-time_stamp)>timeout_val)
		{
			return 2; //device timed out, take care of error handling in the calling function.
		}
	}

	return (TWSR & 0xf8); //return the status code
}


unsigned char i2c_receive(unsigned char acknowledge, uint8_t *data)
{
	if(acknowledge) //if it is the last byte then send a NACK
		TWCR = (1<<TWEN) | (1<<TWINT);
	else //if it is not the last byte Transmit a ACK
		TWCR = (1<<TWEN) | (1<<TWEA) | (1<<TWINT);

	time_stamp=millis();
	
	while(!(TWCR & (1<<TWINT))) //wait until operation is complete by polling TWINT flag.
	{
		if((millis()-time_stamp)>timeout_val)
		{
			return 2; //device timed out, take care of error handling in the calling function.
		}
	}
	
	*data = TWDR;
	return 1;
}


unsigned char i2c_tx_sla_r(unsigned char address)
{
	//Transmit the 7 bit address by appending 1 at the end
	return i2c_transmit((address<<1) | (1<<0)); //and return the status code
}

unsigned char i2c_tx_sla_w(unsigned char address)
{
	//Transmit the 7 bit address by appending 0 at the end
	return i2c_transmit(address<<1); //and return the status code
}


uint8_t i2c_write(uint8_t address, uint8_t reg, uint8_t *data, uint8_t bytes)
{
		i2c_start();
		
		i2c_tx_sla_w(address);
		
		i2c_transmit(reg);
		
		for(uint8_t i=0;i<bytes;i++)
		{
			i2c_transmit(data[i]);
		}
	
		i2c_stop();
	
	return 1; //return 2 if timed-out
}


uint8_t i2c_read(uint8_t address, uint8_t reg, uint8_t *data, uint8_t bytes)
{
		i2c_start();
		
		i2c_tx_sla_w(address);
	
		i2c_transmit(reg);
	
		i2c_rep_start();
			
		i2c_tx_sla_r(address);
			
		for(uint8_t i=0;i<bytes;i++)
		{
			if(i!=bytes-1)
			{
				i2c_receive(ACK,&data[i]);
			}
			else
			{
				i2c_receive(NACK,&data[i]);
			}
		}
			
		i2c_stop();
	
	return 1;//return 2 if timed-out	
}
